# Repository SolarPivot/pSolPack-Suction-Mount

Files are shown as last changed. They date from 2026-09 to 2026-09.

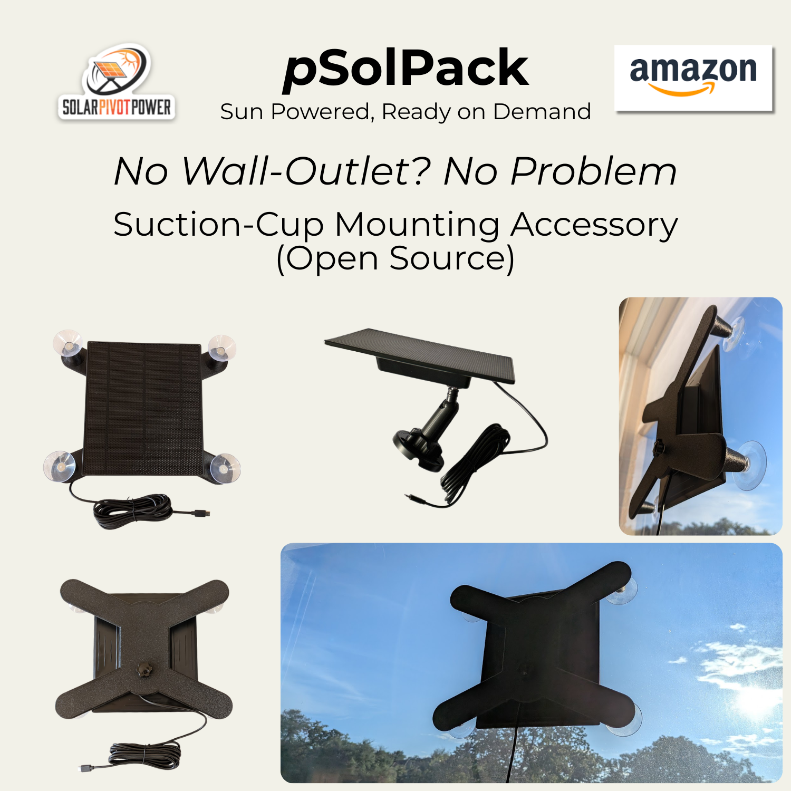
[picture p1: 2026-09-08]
pSolPack Suction Cup Mount.png

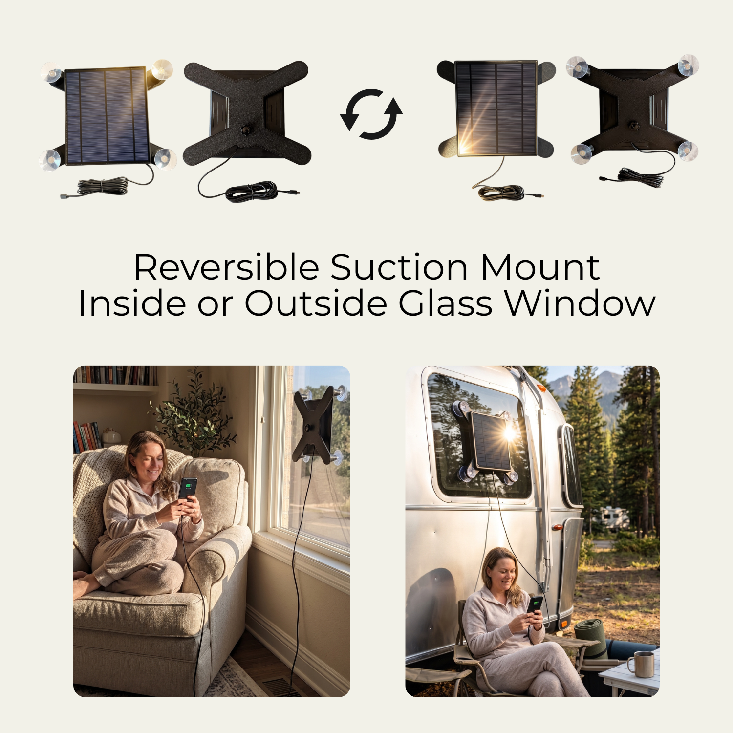
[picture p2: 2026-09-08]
pSolPack Suction Cup Mount Inside Outside Window.png

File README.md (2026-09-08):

# pSolPack-Suction-Mount
pSolPack Suction-Mount DIY Accessory

Mount pSolPack (5W/8000mAh) solar with battery IP-65 enclosure inside or outside any glass window

STL: 3D Printable

PDF: Assembly & Setup Guide

# Off the Shelf Parts (Amazon Links)

Suction Cups: https://a.co/d/02Eb7gs4

1.4" Knurled Bolt: https://a.co/d/02taQniU

M4 Square Nuts: https://a.co/d/0eEPxn61

1/4" Split Washer: https://a.co/d/0bZC6Kos

# Note: Do Not Mount Outside Window in a moving car.

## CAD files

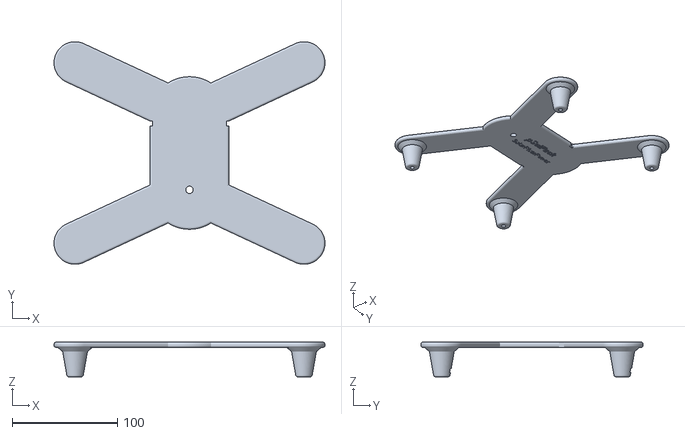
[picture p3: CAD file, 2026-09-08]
Suction Mount.stl
257.5 x 211.4 x 33.0

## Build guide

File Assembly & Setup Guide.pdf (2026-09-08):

## 1: BOM & Part Preparation #2: Part Assembly

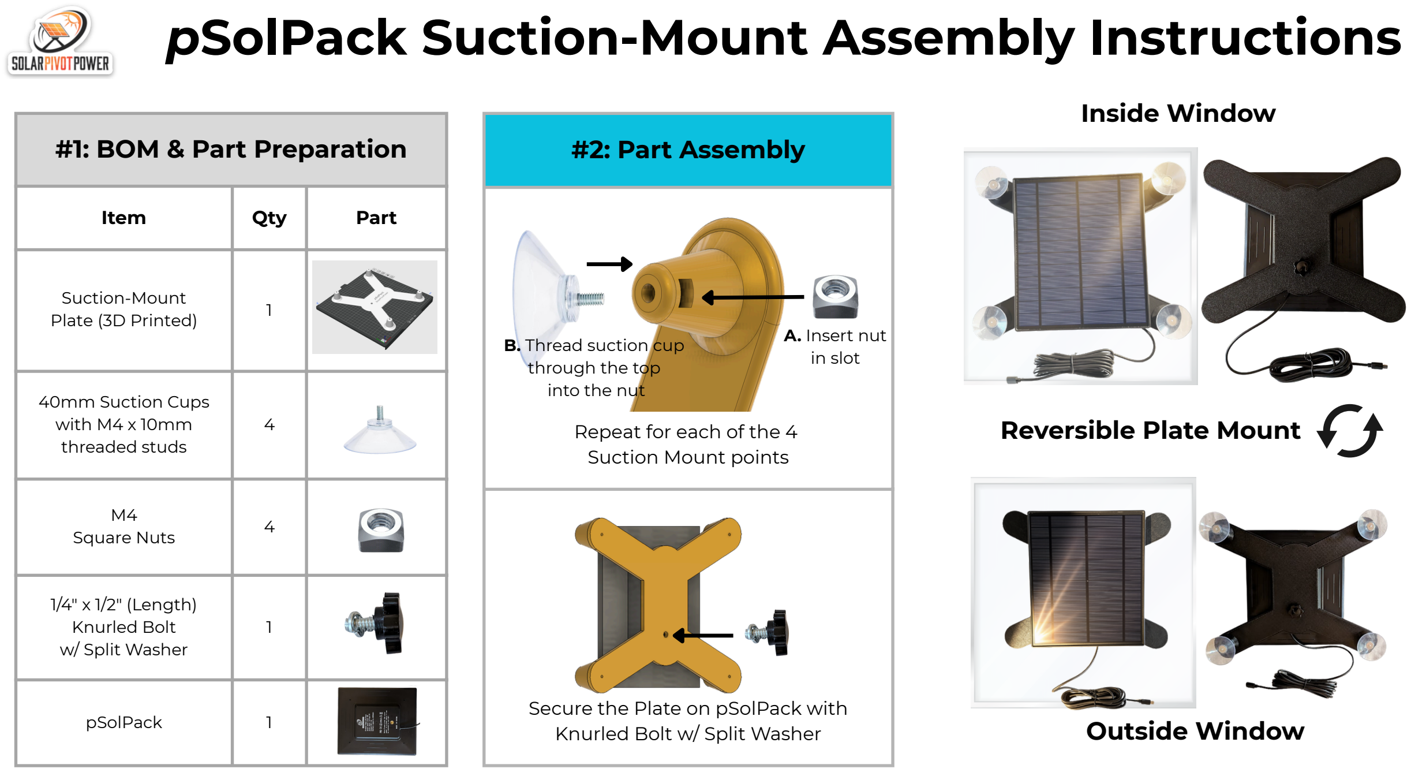
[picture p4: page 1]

Item | Qty | Part
Suction-Mount Plate (3D Printed) | 1
40mm Suction Cups with M4 x 10mm threaded studs | 4
M4 Square Nuts | 4
1/4" x 1/2" (Length) Knurled Bolt w/ Split Washer | 1
pSolPack | 1

Repeat for each of the 4
Suction Mount points

Secure the Plate on pSolPack with Knurled Bolt w/ Split Washer

# pSolPack Suction-Mount Assembly Instructions

## Reversible Plate Mount

## Inside Window

## Outside Window

A. Insert nut
in slot
B. Thread suction cup
through the top
into the nut

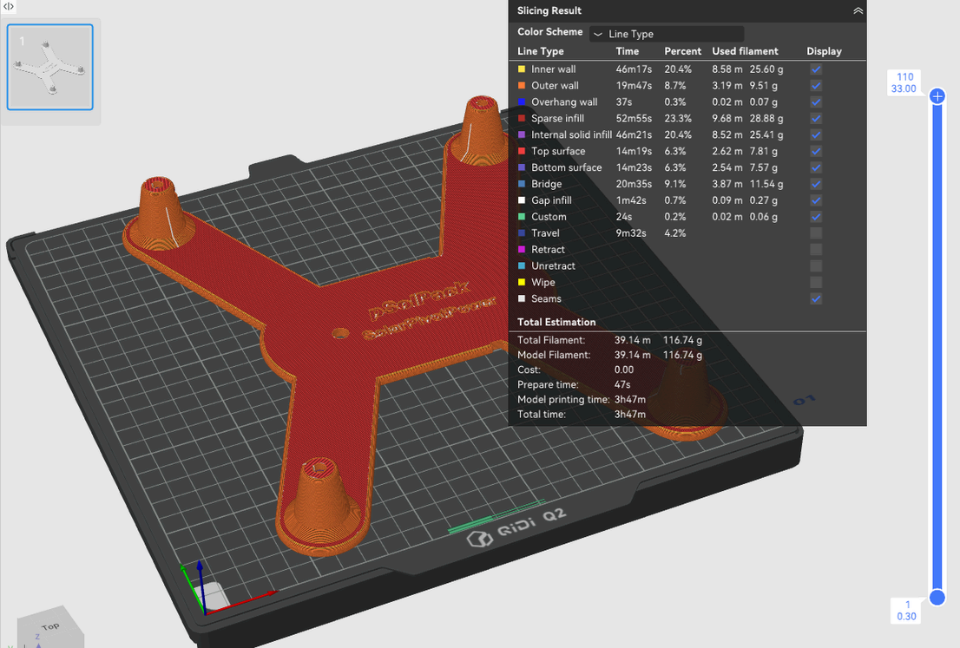
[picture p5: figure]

# 3D Print Elements

Nozzle | 0.6mm Hardened
Filament | PETG-GF or PETG-CF
Print Time | 3-4 Hours
Supports | None
